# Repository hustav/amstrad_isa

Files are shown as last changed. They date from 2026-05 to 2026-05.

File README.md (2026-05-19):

# Amstrad PPC 512/640 — ISA Expansion Board

An open-hardware **KiCad 8** design for an external-mount, internally-powered
**3-slot XT-class (8-bit) ISA expansion board** for the Amstrad PPC 512 and
PPC 640 portable PCs.

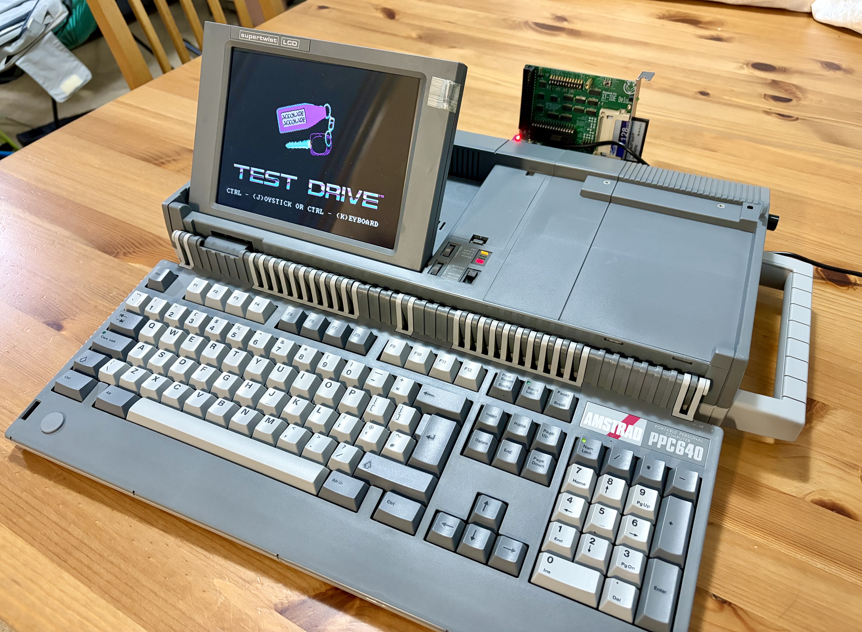
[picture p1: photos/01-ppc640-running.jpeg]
Amstrad PPC 640 running with the ISA expansion board attached


The PPC is the 1988-era Amstrad luggable that ships with a CMOS-level
expansion connector (DB25 + DB37) on its back. Amstrad sold an external
"Expansion Box" that was meant to *power* the PPC and add peripheral slots.
This project inverts the original topology: it **takes power from the PPC's
own PSU** and gives you three standard XT 8-bit ISA slots in a compact board
that clips onto the back of the machine via the two DB connectors — ready to
host modern flash-based peripherals (XT-IDE, floppy emulators, network
cards, etc.).

## Gallery

The board has been fabricated and tested in a real Amstrad PPC 640 —
booting DOS from a CompactFlash card via an XT-IDE controller. Photos
below are of the assembled board in service.

| | |
|---|---|
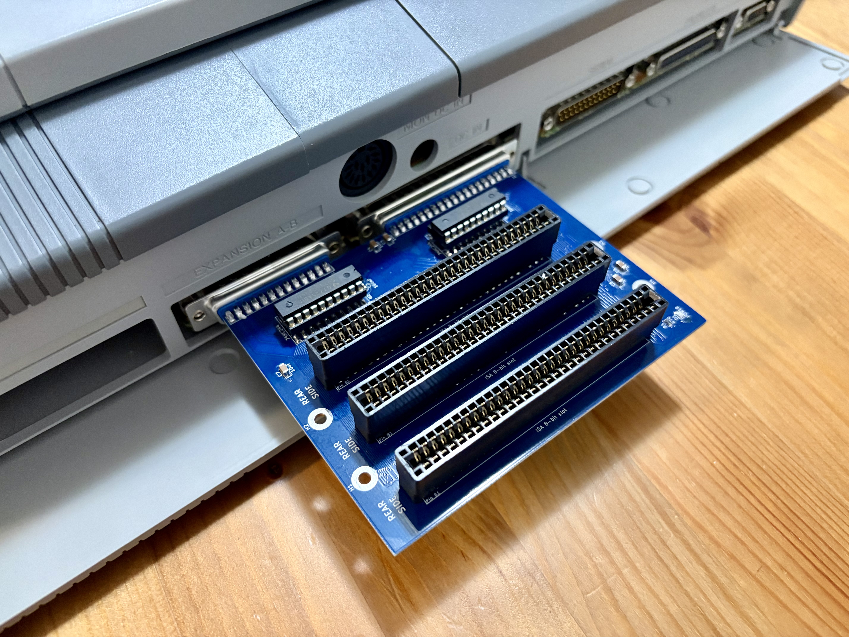
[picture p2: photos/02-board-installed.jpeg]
Bare board installed on the PPC back
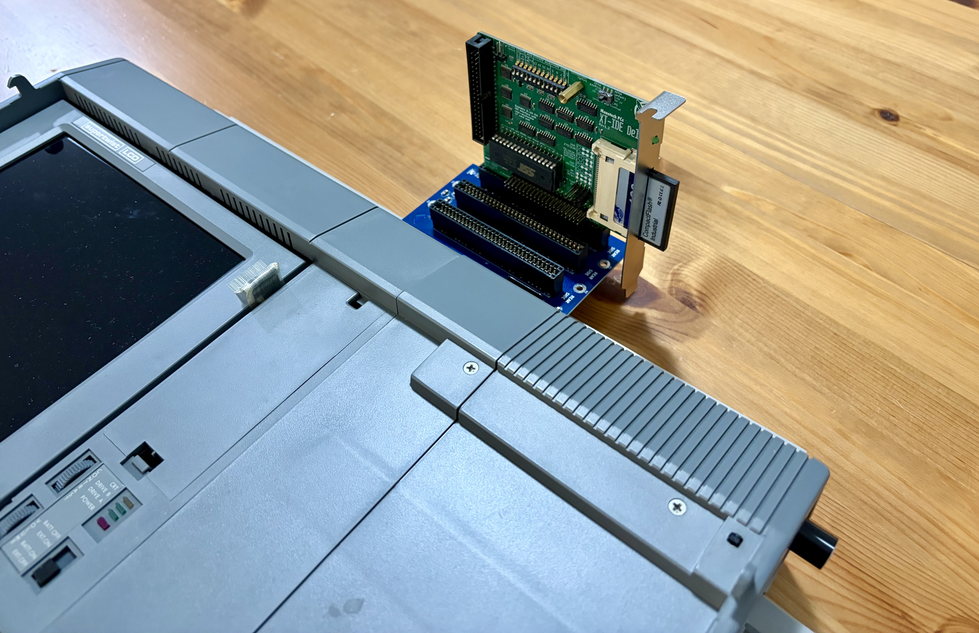
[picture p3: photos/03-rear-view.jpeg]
Rear view, board attached
|  |  |
| Board mated to the PPC's DB25 + DB37 expansion port. | Top-down view showing the three ISA slots fanning out the back. |
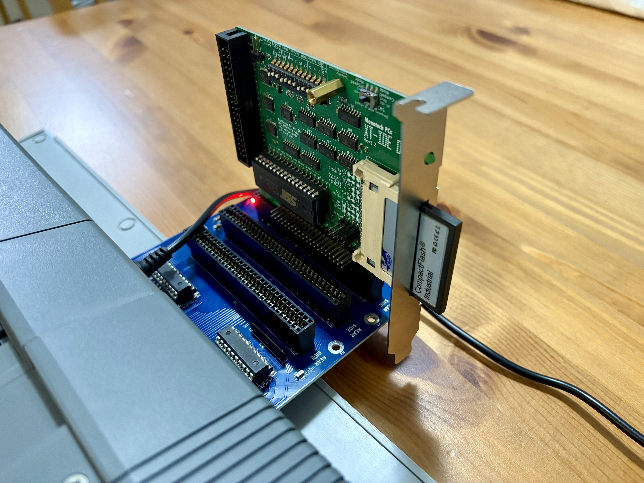
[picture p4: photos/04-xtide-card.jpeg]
XT-IDE with CF card installed in slot
|  | PPC 640 booting from CF via XT-IDE |
| XT-IDE card with CompactFlash plugged into the centre slot. | The PPC 640 booting and running Test Drive from the CF card. |

## Repository layout

```
amstrad_isa/
├── README.md                  — this file
├── LICENSE                    — MIT
├── .gitignore                 — KiCad / Python / OS cruft
├── kicad/
│   ├── ppc-isa-expansion.kicad_pro
│   ├── ppc-isa-expansion.kicad_sch
│   ├── ppc-isa-expansion.kicad_pcb
│   ├── sym-lib-table          — project-local symbol libraries
│   ├── fp-lib-table           — project-local footprint libraries
│   └── ppc-isa.pretty/        — custom ISA 8-bit slot footprint
├── scripts/
│   ├── generate_schematic.py  — regenerates the schematic from tables
│   ├── generate_pcb.py        — regenerates the PCB skeleton
│   └── generate_bom.py        — emits docs/BOM.csv
├── fab/                       — ready-to-order gerbers + JLCPCB zip
├── docs/
│   ├── design_notes.md        — the *why* behind the schematic choices
│   ├── BOM.csv                — bill of materials
│   └── Amstrad_PPC_Technical_Reference_Manual.pdf
└── photos/                    — build & in-machine reference shots
```

## I just want a board — no KiCad

If you don't want to install KiCad, the [`fab/`](fab/) folder contains a
ready-to-order gerber set straight from the committed `.kicad_pcb`.

1. Download [`fab/ppc-isa-expansion-gerbers.zip`](fab/ppc-isa-expansion-gerbers.zip)
   (no need to extract it).
2. Go to your favourite board house — **JLCPCB**, **PCBWay**, **OSH Park**
   and **Aisler** all accept this format unchanged.
3. Upload the zip. The defaults are fine: 2 layers, 1.6 mm FR-4, HASL or
   ENIG finish, any colour. Quantity 5 is usually the minimum and runs
   ~$5 + shipping.
4. Order, wait, populate from [`docs/BOM.csv`](docs/BOM.csv).

The gerbers in `fab/` always match the committed `.kicad_pcb`. If you fork
and re-route, re-plot from KiCad and replace the contents of `fab/`.

## Build from source (with KiCad)

```bash
git clone git@github.com:hustav/amstrad_isa.git
cd amstrad_isa

# Optional: regenerate the schematic / PCB from the Python source of truth
python3 scripts/generate_schematic.py
python3 scripts/generate_pcb.py

# Open the project
kicad kicad/ppc-isa-expansion.kicad_pro
```

The `.kicad_sch` and `.kicad_pcb` files were initially **generated** by the
scripts in `scripts/` — those scripts remain the source of truth for the
netlist. The current `.kicad_pcb` has been routed by hand on top of that
skeleton, so re-running `generate_pcb.py` would overwrite the routing.
If you need to change the netlist, regenerate the skeleton and then redo
the affected traces.

## Key design choices

| Area | Choice | Reason |
| --- | --- | --- |
| Form factor | External-mount, ~120 × 99 mm | Clips onto the PPC's DB25 + DB37 expansion port |
| Slots | 3 × XT 8-bit ISA (62-pin) | Standard pinout, matches prior-art boards |
| Power source | Drawn from the PPC's internal PSU via the expansion cable | No external brick required |
| −5 V rail | Taken directly from connector B pin 17 | Tech Ref §1.18 confirms PPC sources −5 V |
| Component style | SMD only — SOIC, 0805, SIP network | Hand-solderable with a fine-tip iron |
| Buffering | 2 × 74HC244 for A00..A07 + 8 control signals | Drives the loaded capacitance of 3 ISA slots |
| Data bus | Unbuffered, 10 kΩ pull-ups via RR1 | Per Amstrad Tech Ref CMOS-to-TTL note |
| Activity LED | Removed (BEAT flip-flop omitted) | Purely cosmetic; saves 1× SOIC-14 + RC bits |

Full rationale lives in [docs/design_notes.md](docs/design_notes.md).

## Power topology — important caveat

The Amstrad PPC Technical Reference Manual (§1.18) states that the original
Expansion Box is intended to *supply* power **to** the PPC, not draw from
it. Connector B pin 20 is an **EXT PWR input** to the PPC's regulator.

This design **reverses that flow** — all four rails (+5 V, +12 V, −5 V,
−12 V) are *drawn* from the PPC's expansion connector:

- +5 V from connector A pin 1 and connector B pin 37
- +12 V from connector B pin 36
- −5 V from connector B pin 17
- −12 V from connector B pin 18

Pin 20 (EXT PWR into the PPC) is **left floating** — voltage is never
injected back into the PPC.

**Safe for modern peripherals.** An original floppy or 10 MB Winchester drew
5–10 W. A flash-based XT-IDE with a CF card draws ~100–200 mA on +5 V
(0.5–1 W). Three flash peripherals are comfortably within the headroom the
original PSU left for the Expansion Box port.

**Not safe for original drives.** If you try to use the original floppy or
HDD controllers through this board, the PPC's PSU may brown out. In that
case, build an externally-powered (ATX) variant instead.

## Amstrad expansion pinout (Tech Ref §1.18)

### Connector A (DB25 male on the board)

Mostly the address bus.

| Pin | Signal | Notes |
| --- | --- | --- |
| 1 | +5 V | **power input** |
| 2 | TC | DMA terminal-count |
| 3, 16, 4, 17, 5, 18, 6, 19, 7, 20, 8, 21 | A19..A08 | Unbuffered |
| 9, 22, 10, 23, 11, 24, 12, 25 | A07b..A00b | Buffered on PPC side; re-buffered by U2 |
| 13 | AEN | Address enable |
| 14 | GND | |
| 15 | DACK0 | |

### Connector B (DB37 male on the board)

Data bus, IRQs, DMA, control signals, power.

| Pin | Signal | Notes |
| --- | --- | --- |
| 1 | −20 V | **unused, left NC** |
| 2–4, 21–23 | IRQ2..IRQ7 | Pass-through |
| 5 | I/O RDY | Pass-through |
| 6, 24–25 | DACK1..DACK3 | Pass-through |
| 7 | I/O CHCK | Pass-through |
| 8, 26–27 | DRQ1..DRQ3 | Pass-through |
| 9 | OSC(b) | 14.318 MHz buffered on PPC side; re-buffered by U1 |
| 10–12, 28–31 | MEMR(b), IOR(b), ALE(b), MEMW(b), IOW(b), RESET(b), CK4(b) | Re-buffered by U1 |
| 13–16, 32–35 | D7..D0 | Unbuffered; 10 kΩ pull-ups via RR1 |
| 17 | −5 V | **power input** |
| 18 | −12 V | **power input** |
| 19 | GND | |
| 20 | EXT PWR | **NOT USED** — would feed the PPC's regulator |
| 36 | +12 V | **power input** |
| 37 | +5 V | **power input** |

The full Amstrad PPC Technical Reference Manual is included in
[docs/](docs/Amstrad_PPC_Technical_Reference_Manual.pdf) for reference.

## Credits and prior art

This design builds on two community projects, both of which are
externally-mounted boards that hang off the PPC's DB25 + DB37 connectors:

- **João (enide.net)** — original internally-powered design. Provided the
  mechanical approach and power topology. Only the gerbers were available
  (the project is currently offline), so the schematic was reverse-
  engineered from those files and cross-referenced against the
  Retrotheory design below.
- **Retrotheory — [amstradppc_expansion](https://github.com/retrotheory/amstradppc_expansion)** —
  ATX-powered variant. Provided the full schematic used as the electrical
  reference (74HC244 pinouts, the BEAT LED divider using a 74HC74, etc.).

Many thanks to both for sharing their work — without them this design
would not exist.

## License

Released under the **MIT License**. See [LICENSE](LICENSE).

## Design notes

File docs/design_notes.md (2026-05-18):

# Design notes - PPC ISA Expansion

This document captures the *why* behind specific schematic decisions that
might not be obvious from the netlist alone.  When in doubt about an
electrical choice, the answer almost always lives here.

## The two 74HC244 buffers

The Amstrad PPC sends some address and control signals onto the
expansion connector through its own 74HC244 (the chip labelled IC102 in
the PPC's main schematic).  Those signals are marked with a `b` suffix
in our netlist (`A00b..A07b`, `OSCb`, `MEMRb`, etc.) - the `b` stands
for *buffered on the PPC side*.

Our board has to **re-buffer** them before sending them onto the ISA
bus, because the loaded capacitance of three ISA slots plus their cards
is way above what the PPC's single buffer is rated for.

| Buffer | Inputs (from Amstrad) | Outputs (to ISA) |
| --- | --- | --- |
| U1 (74HC244 SOIC-20) | OSCb, CK4b, MEMRb, MEMWb, IORb, IOWb, ALEb, RESETb | OSC, CLK, ~SMEMR, ~SMEMW, ~IOR, ~IOW, ALE, RESET |
| U2 (74HC244 SOIC-20) | A07b, A06b, A05b, A04b, A03b, A02b, A01b, A00b | A07, A06, A05, A04, A03, A02, A01, A00 |

The other 12 address bits (A08..A19) are *not* buffered on the PPC side,
so we let them pass straight through from the DB25 to the ISA slots.

Both buffers have their `~OE` pins tied to GND - the buffers are
permanently enabled.  This is identical to project 2's topology.

## The data bus is unbuffered

D0..D7 on connector B pin 13-16 and 32-35 come out of the PPC at CMOS
levels.  Per the PPC tech-ref note: "to interface with TTL devices,
each line should be pulled up to +5V via a 10K resistor".  That's the
only "buffering" the data bus gets - 10K pull-ups via the `RR1` SIP
resistor network.

The data bus is bidirectional, so a real transceiver (like a 74HC245)
would be needed to drive it from the ISA side back to the PPC side.
**Project 2 also omits this, and so do we** - the assumption being that
ISA peripherals will source enough drive to overcome the pull-ups when
they need to read data back to the host.  For a flash-based XT-IDE
this works in practice; for a fully loaded slot of three active cards
you may want to add a 74HC245 in a future revision.

## The BEAT LED (removed)

Project 2 had a 74HCT74 dual flip-flop (U4) configured as a toggle,
clocked by A07, driving a "BEAT" LED through a 470 ohm resistor.  The
result was a heartbeat that flickered whenever the CPU was active.

**We do not carry this over.**  It's purely cosmetic - the board works
identically without it.  Dropping U4 saves one SOIC-14, two 1K
pull-ups (`~1CLR_BEAT`, `~1PRE_BEAT`), the 470R series resistor, the
LED itself, and one decoupling cap.

If you want to restore it later, look at the git history for the
`U4_NETS` table and the commented removal block in
`scripts/generate_schematic.py` - everything needed is self-contained
and easy to add back.

## Power LED

`D1_PWR` connects from +5V through 470 ohm to GND.  Whenever the PPC
is on and the cable is plugged in, this lights.

## Ground star

The four mounting holes are pad-and-plated through-hole, all tied to
GND.  This serves three purposes:

1. Mechanical mounting (M3 screws into the PPC chassis)
2. Electrical bond to chassis ground
3. Star-ground point distribution to reduce loop area on the SMD layer

## Net classes

- **Default**: 0.25 mm tracks, 0.2 mm clearance
- **Power**: 0.5 mm tracks, 0.3 mm clearance, applied to +5V/+12V/-5V/-12V/GND

These are conservative for a low-current digital board and are well
within JLCPCB / OSH Park / PCBWay capabilities at standard pricing.

## Notes on the routed PCB

The committed `.kicad_pcb` has been routed by hand on top of the
generator's skeleton.  A few things worth knowing if you intend to fork
or re-spin it:

- **Ground pours** are present on the back copper layer; the front copper
  layer relies on traces only.
- **Stitching vias** along the board edges are sparse - add more if you
  are chasing EMI compliance.
- **Silkscreen labels** are the auto-generated reference designators and
  values; feel free to polish before sending to fab.
- If you re-run `generate_pcb.py` the skeleton is rewritten and the
  routing is lost - back up the `.kicad_pcb` first.

## Footprint substitutions

KiCad 8 does not ship a dedicated ISA 8-bit card-edge socket in its
standard libraries, so this project includes a custom one in
`kicad/ppc-isa.pretty/ISA_8Bit_Slot.kicad_mod`.  The library is
registered in `kicad/fp-lib-table` as the project-local library
`ppc-isa`, so the three ISA slots resolve as `ppc-isa:ISA_8Bit_Slot`.

If you don't have one of the other footprints installed, equivalent
options are:

| Generated footprint | Drop-in alternative |
| --- | --- |
| `ppc-isa:ISA_8Bit_Slot` | Any 2x31 0.1" pin socket (the actual part is a 62-way card-edge socket such as TE 5352155-1 or equivalent).  For prototyping, a 2x31 pin socket works - the pad pattern is identical |
| `Connector_Dsub:DSUB-25_Male_Horizontal_P2.77x2.84mm_EdgePinOffset4.94mm` | Any horizontal-mount DB25 male (right-angle PCB version) |
| `Package_SO:SOIC-20W_7.5x12.8mm_P1.27mm` | The wide-body SOIC-20; the narrow-body SOIC-20 (300 mil) also fits with manual landpattern adjustment |
| `Resistor_THT:R_Array_SIP9` | Bourns 4609X / Yageo equivalents - check pin 1 orientation |

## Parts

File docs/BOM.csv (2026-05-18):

References | Quantity | Value | Footprint | Description | Notes
U1, U2 | 2 | 74HC244 | Package_SO:SOIC-20W_7.5x12.8mm_P1.27mm | Octal bus buffer / line driver, non-inverting | SOIC-20 wide body; any 74HC244 or 74HCT244 works
C1, C2, C3, C4, C5 | 5 | 100nF | Capacitor_SMD:C_0805_2012Metric | Chip capacitor, X7R ceramic | 0805; 50V rating
C6, C7, C8, C9 | 4 | 10uF | Capacitor_SMD:C_0805_2012Metric | Chip capacitor, X7R ceramic | 0805; 50V rating
J1 | 1 | DB25 Male | Connector_Dsub:DSUB-25_Male_Horizontal_P2.77x2.84mm_EdgePinOffset4.94mm_Housed_MountingHolesOffset7.48mm | D-sub 25-pin male, right-angle PCB mount | mates with Amstrad Expansion Connector A
J2 | 1 | DB37 Male | Connector_Dsub:DSUB-37_Male_Horizontal_P2.77x2.84mm_EdgePinOffset4.94mm_Housed_MountingHolesOffset7.48mm | D-sub 37-pin male, right-angle PCB mount | mates with Amstrad Expansion Connector B
J3, J4, J5 | 3 | ISA 8-bit slot | Connector:ISA_Slot_8bit_2x31_P2.54mm_Vertical | XT 8-bit ISA slot (62-pin card-edge socket) | 2x31 on 2.54 mm pitch; 5.08 mm between rows
D1_PWR | 1 | LED_POWER | LED_SMD:LED_0805_2012Metric | Chip LED | 0805; choose visible colour (green/red/amber)
R101 | 1 | 470 | Resistor_SMD:R_0805_2012Metric | Chip resistor | 0805 (2012 metric); +/-1% or 5% is fine
RR1 | 1 | 10k | Resistor_THT:R_Array_SIP9 | 9-pin SIP resistor network (8 bussed resistors) | 10K value; Bourns 4609X-101-103 or equivalent

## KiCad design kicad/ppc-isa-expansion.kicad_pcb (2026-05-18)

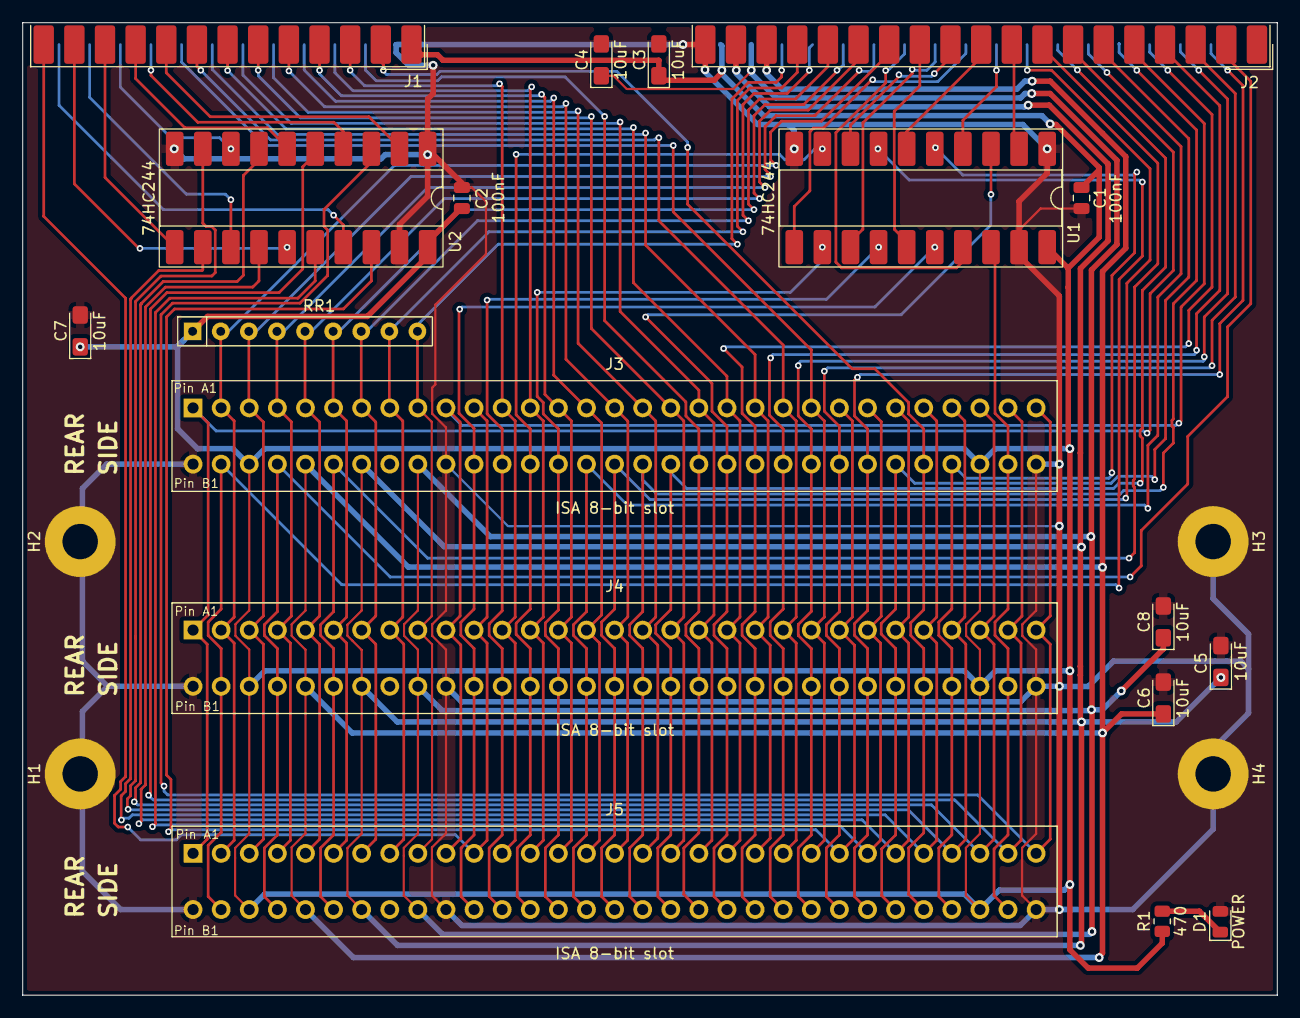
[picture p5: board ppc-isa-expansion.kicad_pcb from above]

Board: 2 copper layers, 113.4 x 87.9 mm, 22 parts (0 on the bottom side), 75 nets.

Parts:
C1, C2: 100nF; C_0805_2012Metric
C3, C4, C5, C6, C7, C8: 10uF; CP_EIA-3216-12_Kemet-S_HandSolder
D1: POWER; LED_0805_2012Metric
H1, H2, H3, H4: MountingHole_M3; MountingHole_3.2mm_M3_Pad
J1: DB25 Male; DSUB-25_Pins_EdgeMount_P2.77mm
J2: DB37 Male; DSUB-37_Pins_EdgeMount_P2.77mm
J3, J4, J5: ISA 8-bit slot; ISA_8Bit_Slot
R1: 470; R_0805_2012Metric
RR1: 10k; R_Array_SIP9
U1, U2: 74HC244; DIP-20_W8.89mm_SMDSocket_LongPads

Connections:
+5V: C1.1, C2.1, C3.1, C7.1, J1.1 (+5V), J2.37 (+5V), J3.34 (+5V), J3.60 (+5V), J4.34 (+5V), J4.60 (+5V), J5.34 (+5V), J5.60 (+5V), R1.1, RR1.1 (COM), U1.20 (VCC), U2.20 (VCC)
+12V: C4.1, C8.1, J2.36 (+12V), J3.40 (+12V), J4.40 (+12V), J5.40 (+12V)
-5V: C6.1, J2.17 (-5V), J3.36 (-5V), J4.36 (-5V), J5.36 (-5V)
-12V: C5.1, J2.18 (-12V), J3.38 (-12V), J4.38 (-12V), J5.38 (-12V)
A00: J3.31 (A00), J4.31 (A00), J5.31 (A00), U2.3 (2Y3)
A00b: J1.25 (A00b), U2.17 (2A3)
A01: J3.30 (A01), J4.30 (A01), J5.30 (A01), U2.5 (2Y2)
A01b: J1.12 (A01b), U2.15 (2A2)
A02: J3.29 (A02), J4.29 (A02), J5.29 (A02), U2.7 (2Y1)
A02b: J1.24 (A02b), U2.13 (2A1)
A03: J3.28 (A03), J4.28 (A03), J5.28 (A03), U2.9 (2Y0)
A03b: J1.11 (A03b), U2.11 (2A0)
A04: J3.27 (A04), J4.27 (A04), J5.27 (A04), U2.12 (1Y3)
A04b: J1.23 (A04b), U2.8 (1A3)
A05: J3.26 (A05), J4.26 (A05), J5.26 (A05), U2.14 (1Y2)
A05b: J1.10 (A05b), U2.6 (1A2)
A06: J3.25 (A06), J4.25 (A06), J5.25 (A06), U2.16 (1Y1)
A06b: J1.22 (A06b), U2.4 (1A1)
A07: J3.24 (A07), J4.24 (A07), J5.24 (A07), U2.18 (1Y0)
A07b: J1.9 (A07b), U2.2 (1A0)
A08: J1.21 (A08), J3.23 (A08), J4.23 (A08), J5.23 (A08)
A09: J1.8 (A09), J3.22 (A09), J4.22 (A09), J5.22 (A09)
A10: J1.20 (A10), J3.21 (A10), J4.21 (A10), J5.21 (A10)
A11: J1.7 (A11), J3.20 (A11), J4.20 (A11), J5.20 (A11)
A12: J1.19 (A12), J3.19 (A12), J4.19 (A12), J5.19 (A12)
A13: J1.6 (A13), J3.18 (A13), J4.18 (A13), J5.18 (A13)
A14: J1.18 (A14), J3.17 (A14), J4.17 (A14), J5.17 (A14)
A15: J1.5 (A15), J3.16 (A15), J4.16 (A15), J5.16 (A15)
A16: J1.17 (A16), J3.15 (A16), J4.15 (A16), J5.15 (A16)
A17: J1.4 (A17), J3.14 (A17), J4.14 (A17), J5.14 (A17)
A18: J1.16 (A18), J3.13 (A18), J4.13 (A18), J5.13 (A18)
A19: J1.3 (A19), J3.12 (A19), J4.12 (A19), J5.12 (A19)
AEN: J1.13 (AEN), J3.11 (AEN), J4.11 (AEN), J5.11 (AEN)
ALE: J3.59 (ALE), J4.59 (ALE), J5.59 (ALE), U1.5 (2Y2)
ALEb: J2.12 (ALEb), U1.15 (2A2)
CK4b: J2.31 (CK4b), U1.17 (2A3)
CLK: J3.51 (CLK), J4.51 (CLK), J5.51 (CLK), U1.3 (2Y3)
D0: J2.35 (D0), J3.9 (D0), J4.9 (D0), J5.9 (D0), RR1.9 (R8)
D1: J2.16 (D1), J3.8 (D1), J4.8 (D1), J5.8 (D1), RR1.8 (R7)
D2: J2.34 (D2), J3.7 (D2), J4.7 (D2), J5.7 (D2), RR1.7 (R6)
D3: J2.15 (D3), J3.6 (D3), J4.6 (D3), J5.6 (D3), RR1.6 (R5)
D4: J2.33 (D4), J3.5 (D4), J4.5 (D4), J5.5 (D4), RR1.5 (R4)
D5: J2.14 (D5), J3.4 (D5), J4.4 (D5), J5.4 (D5), RR1.4 (R3)
D6: J2.32 (D6), J3.3 (D6), J4.3 (D6), J5.3 (D6), RR1.3 (R2)
D7: J2.13 (D7), J3.2 (D7), J4.2 (D7), J5.2 (D7), RR1.2 (R1)
DRQ1: J2.26 (DRQ1), J3.49 (DRQ1), J4.49 (DRQ1), J5.49 (DRQ1)
DRQ2: J2.8 (DRQ2), J3.37 (DRQ2), J4.37 (DRQ2), J5.37 (DRQ2)
DRQ3: J2.27 (DRQ3), J3.47 (DRQ3), J4.47 (DRQ3), J5.47 (DRQ3)
GND: C1.2, C2.2, C3.2, C4.2, C5.2, C6.2, C7.2, C8.2, D1.2 (A), H1.1, H2.1, H3.1, H4.1, J1.14 (GND), J2.19 (GND), J3.32 (GND), J3.41 (GND), J3.62 (GND), J4.32 (GND), J4.41 (GND), J4.62 (GND), J5.32 (GND), J5.41 (GND), J5.62 (GND), U1.1 (~1OE), U1.10 (GND), U1.19 (~2OE), U2.1 (~1OE), U2.10 (GND), U2.19 (~2OE)
IO_RDY: J2.5 (IO_RDY), J3.10 (IO_RDY), J4.10 (IO_RDY), J5.10 (IO_RDY)
IRQ2: J2.2 (IRQ2), J3.35 (IRQ2), J4.35 (IRQ2), J5.35 (IRQ2)
IRQ3: J2.21 (IRQ3), J3.56 (IRQ3), J4.56 (IRQ3), J5.56 (IRQ3)
IRQ4: J2.3 (IRQ4), J3.55 (IRQ4), J4.55 (IRQ4), J5.55 (IRQ4)
IRQ5: J2.22 (IRQ5), J3.54 (IRQ5), J4.54 (IRQ5), J5.54 (IRQ5)
IRQ6: J2.4 (IRQ6), J3.53 (IRQ6), J4.53 (IRQ6), J5.53 (IRQ6)
IRQ7: J2.23 (IRQ7), J3.52 (IRQ7), J4.52 (IRQ7), J5.52 (IRQ7)
unnamed: D1.1 (K), R1.2
OSC: J3.61 (OSC), J4.61 (OSC), J5.61 (OSC), U1.18 (1Y0)
OSCb: J2.9 (OSCb), U1.2 (1A0)
RESET: J3.33 (RESET), J4.33 (RESET), J5.33 (RESET), U1.7 (2Y1)
RESETb: J2.30 (RESETb), U1.13 (2A1)
TC: J1.2 (TC), J3.58 (TC), J4.58 (TC), J5.58 (TC)
~DACK0: J1.15 (~DACK0), J3.50 (~DACK0), J4.50 (~DACK0), J5.50 (~DACK0)
~DACK1: J2.24 (~DACK1), J3.48 (~DACK1), J4.48 (~DACK1), J5.48 (~DACK1)
~DACK2: J2.6 (~DACK2), J3.57 (~DACK2), J4.57 (~DACK2), J5.57 (~DACK2)
~DACK3: J2.25 (~DACK3), J3.46 (~DACK3), J4.46 (~DACK3), J5.46 (~DACK3)
~IOCHCK: J2.7 (~IOCHCK), J3.1 (~IOCHCK), J4.1 (~IOCHCK), J5.1 (~IOCHCK)
~IOR: J3.45 (~IOR), J4.45 (~IOR), J5.45 (~IOR), U1.12 (1Y3)
~IORb: J2.11 (~IORb), U1.8 (1A3)
~IOW: J3.44 (~IOW), J4.44 (~IOW), J5.44 (~IOW), U1.9 (2Y0)
~IOWb: J2.29 (~IOWb), U1.11 (2A0)
~MEMRb: J2.10 (~MEMRb), U1.6 (1A2)
~MEMWb: J2.28 (~MEMWb), U1.4 (1A1)
~SMEMR: J3.43 (~SMEMR), J4.43 (~SMEMR), J5.43 (~SMEMR), U1.14 (1Y2)
~SMEMW: J3.42 (~SMEMW), J4.42 (~SMEMW), J5.42 (~SMEMW), U1.16 (1Y1)

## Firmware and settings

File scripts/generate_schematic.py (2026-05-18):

#!/usr/bin/env python3
"""
Generate a KiCad 8 schematic (.kicad_sch) for the Amstrad PPC ISA Expansion board.

Strategy
--------
Rather than hand-wiring the schematic (which would be visually intricate and
error-prone to generate programmatically), we produce a grid of component
blocks where every pin is connected to a **global label** carrying the net
name. This guarantees electrical correctness — any two pins with the same
global label are on the same net, regardless of visual proximity.

The user can open the resulting file in KiCad 8 and either:
  - use it as-is (it's a complete, valid schematic), or
  - rearrange / re-wire visually while keeping all global labels (electrical
    connectivity is preserved through label names).

Symbols
-------
We embed minimal symbol definitions (`lib_symbols` block) for each part we
use. These are stubs with correct pin count / pin number / electrical type,
drawn as simple rectangles. The user can replace any of them with richer
library symbols (e.g. from the official 74xx and Connector libraries) at
any time — KiCad will update the instance when the `lib_id` resolves.
"""

from __future__ import annotations

import uuid
from dataclasses import dataclass, field
from pathlib import Path
from typing import Iterable

# ---------------------------------------------------------------------------
# UUID helpers — deterministic, so re-running the script gives the same file.
# ---------------------------------------------------------------------------
NAMESPACE = uuid.UUID("12345678-1234-5678-1234-567812345678")

def u(name: str) -> str:
    return str(uuid.uuid5(NAMESPACE, name))


# ---------------------------------------------------------------------------
# Symbol-stub generation
# ---------------------------------------------------------------------------
# Each stub is drawn as a simple rectangle with pins on the left and right.
# Pin electrical types: input, output, bidirectional, power_in, power_out,
# passive, unspecified, open_collector, open_emitter, no_connect.
# ---------------------------------------------------------------------------

def make_stub(lib_name: str, ref_prefix: str,
              left_pins: list[tuple[str, str, str]],
              right_pins: list[tuple[str, str, str]],
              value: str = None,
              extends: str = None,
              show_pin_numbers: bool = True,
              show_pin_names: bool = True) -> str:
    """Generate a minimal lib_symbol stub.

    Each pin is (number, name, etype).  Pins on the left side are drawn with
    length 2.54 going right (orientation 0), on the right side with length
    2.54 going left (orientation 180).  The body is a rectangle sized to fit.
    """
    if value is None:
        value = lib_name.split(":")[-1]
    n_rows = max(len(left_pins), len(right_pins))
    # Body sized 20.32 mm wide (8 grid units), height = n_rows * 2.54 + 5.08
    body_h = n_rows * 2.54 + 5.08
    body_w = 25.4
    left_x = -body_w / 2
    right_x = body_w / 2
    top_y = body_h / 2
    bot_y = -body_h / 2

    pins_out = []
    for i, (num, name, etype) in enumerate(left_pins):
        y = top_y - 2.54 - i * 2.54
        # Pin extends from (left_x - 2.54, y) to (left_x, y), pointing right (angle 0)
        pins_out.append(
            f'    (pin {etype} line (at {left_x - 2.54:.2f} {y:.2f} 0) (length 2.54)\n'
            f'      (name "{name}" (effects (font (size 1.0 1.0))))\n'
            f'      (number "{num}" (effects (font (size 1.0 1.0))))\n'
            f'    )'
        )
    for i, (num, name, etype) in enumerate(right_pins):
        y = top_y - 2.54 - i * 2.54
        # Pin extends from (right_x + 2.54, y) to (right_x, y), pointing left (angle 180)
        pins_out.append(
            f'    (pin {etype} line (at {right_x + 2.54:.2f} {y:.2f} 180) (length 2.54)\n'
            f'      (name "{name}" (effects (font (size 1.0 1.0))))\n'
            f'      (number "{num}" (effects (font (size 1.0 1.0))))\n'
            f'    )'
        )

    body = (
        f'    (rectangle\n'
        f'      (start {left_x:.2f} {bot_y:.2f})\n'
        f'      (end {right_x:.2f} {top_y:.2f})\n'
        f'      (stroke (width 0.254) (type default))\n'
        f'      (fill (type background))\n'
        f'    )'
    )

    pin_numbers_line = '(pin_numbers hide)' if not show_pin_numbers else '(pin_numbers)'
    pin_names_line = '(pin_names hide)' if not show_pin_names else '(pin_names (offset 1.016))'

    sym = (
        f'  (symbol "{lib_name}"\n'
        f'    {pin_numbers_line}\n'
        f'    {pin_names_line}\n'
        f'    (exclude_from_sim no)\n'
        f'    (in_bom yes)\n'
        f'    (on_board yes)\n'
        f'    (property "Reference" "{ref_prefix}" (at 0 {top_y + 2.5:.2f} 0) (effects (font (size 1.27 1.27))))\n'
        f'    (property "Value" "{value}" (at 0 {bot_y - 2.5:.2f} 0) (effects (font (size 1.27 1.27))))\n'
        f'    (property "Footprint" "" (at 0 0 0) (effects (font (size 1.27 1.27)) hide))\n'
        f'    (property "Datasheet" "" (at 0 0 0) (effects (font (size 1.27 1.27)) hide))\n'
        f'    (property "Description" "" (at 0 0 0) (effects (font (size 1.27 1.27)) hide))\n'
        f'    (symbol "{lib_name}_0_1"\n'
        f'{body}\n'
        f'    )\n'
        f'    (symbol "{lib_name}_1_1"\n'
        + '\n'.join(pins_out) + '\n'
        f'    )\n'
        f'  )'
    )
    return sym


# ---------------------------------------------------------------------------
# Pin-type shorthand
# ---------------------------------------------------------------------------
IN = "input"
OUT = "output"
BI = "bidirectional"
PI = "power_in"
PO = "power_out"
PS = "passive"
NC = "no_connect"
U  = "unspecified"


# ---------------------------------------------------------------------------
# Component / pin definitions
# ---------------------------------------------------------------------------

# -- Amstrad DB25 male (Connector A) ------------------------------------------
# From Tech Ref §1.18
DB25_PINS = [
    ("1",  "+5V",     PI),   # pin 1 is +5V INPUT to the expansion board (= power coming from PPC)
    ("2",  "TC",      IN),
    ("3",  "A19",     IN),
    ("4",  "A17",     IN),
    ("5",  "A15",     IN),
    ("6",  "A13",     IN),
    ("7",  "A11",     IN),
    ("8",  "A09",     IN),
    ("9",  "A07b",    IN),   # * buffered
    ("10", "A05b",    IN),
    ("11", "A03b",    IN),
    ("12", "A01b",    IN),
    ("13", "AEN",     IN),
    ("14", "GND",     PI),
    ("15", "~DACK0",  IN),
    ("16", "A18",     IN),
    ("17", "A16",     IN),
    ("18", "A14",     IN),
    ("19", "A12",     IN),
    ("20", "A10",     IN),
    ("21", "A08",     IN),
    ("22", "A06b",    IN),
    ("23", "A04b",    IN),
    ("24", "A02b",    IN),
    ("25", "A00b",    IN),
]
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

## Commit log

2026-05-18 Initial commit: KiCad 8 design + docs + photos
    [BOM.csv, ppc-isa-expansion.kicad_pcb, ppc-isa-expansion.kicad_sch]
2026-05-19 Add fab/ with ready-to-order gerbers
    [ppc-isa-expansion-B_Cu.gbr, ppc-isa-expansion-B_Mask.gbr, ppc-isa-expansion-B_Paste.gbr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]
